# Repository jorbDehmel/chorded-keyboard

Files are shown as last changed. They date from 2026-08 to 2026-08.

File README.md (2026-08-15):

# USB-C Chorded Keyboard

Jordan Dehmel, 2026, MIT license

## About

This is a 10-key, one-handed chorded USB-C keyboard using a
scheme I made up. Each finger is responsible for two keys:
up and down. Only one is expected to be pressed down at a time.
Therefore, each of the 5 fingers has 3 states, leading to
$3^5 = 243$ combinations ($242$ if you don't count the empty
configuration). A chord will be denoted by a 5-character string,
with `U` meaning up, `D` meaning down, and `0` or space meaning
none. I will assume that the keyboard is being used in the left
hand, because I use a mouse in my right hand and therefore the
left is free. As such, we will use the string "`UUDD0`" to
denote the chord "pinky up, ring finger up, middle finger down,
pointer finger down, thumb not pressing either". We will use the
same string, even if the keyboard is being used in right-handed
mode.

The encoding scheme is really a separate project for me, I've
previously written drivers supporting it on QWERTY keyboards. I
just thought it would be cool to have a real version. This
keyboard is both chorded (each keystroke requires multiple
keys to be pressed) and corded (it is not bluetooth).

(If you're wondering why the pinky keys are so low, my
pinkies are just like that! They can't even reach the number
row or backslash on a regular keyboard.)

## The Schema

The idea with the included schema is to mimic the left hand's
QWERTY operations on home row and the row above as closely as
possible. The thumb is used to signify that the chord is
complete. Pressing down with the thumb is for regular
characters, while up is for unusual characters. In situations
where the regular character is not reachable on the two rows we
have access to, I've tried to make the chord look like an arrow
pointing to that character (for instance, "v" takes the chord
"`00UD D`", corresponding to pressing "r" and "f" at the same
time in QWERTY). For characters typed by the right hand in
QWERTY, I usually have a non-adjacent finger press some lower
key (for instance, "`D00D D`" for "j"). These can be combined
(for instance, "`D0DD D`" for "h" based on "`00DD D`" for "g").

 Chord    | Character
----------|-----------------------------------------------------
 `0000 U` | tab
 `000U U` | 8
 `000D U` | right arrow
 `00U0 U` | 4
 `00D0 U` | up arrow
 `0U00 U` | 2
 `0UU0 U` | 6
 `0D00 U` | down arrow
 `0DD0 U` | windows (or corresponding)
 `U000 U` | 1
 `U00U U` | 9
 `U0U0 U` | 5
 `UU00 U` | 3
 `UUU0 U` | 7
 `UUUU U` | escape
 `D000 U` | left arrow
 `DDDD U` | caps lock
 `0000 D` | space
 `000U D` | r
 `000D D` | f
 `00U0 D` | e
 `00UU D` | enter
 `00UD D` | v
 `00D0 D` | d
 `00DU D` | t
 `00DD D` | g
 `0U00 D` | w
 `0UU0 D` | backspace
 `0UUU D` | 0
 `0UD0 D` | c
 `0D00 D` | s
 `U000 D` | q
 `U00D D` | p
 `UD00 D` | x
 `UDUD D` | z
 `D000 D` | a
 `D00U D` | u
 `D00D D` | j
 `D0U0 D` | i
 `D0UD D` | b
 `D0D0 D` | k
 `D0DU D` | y
 `D0DD D` | h
 `DU00 D` | o
 `DUD0 D` | n
 `DUDU D` | m
 `DD00 D` | l

## The Physical Keyboard

This section describes how to assemble the core keyboard. This
is not ergonomic at all because it is intended to be modular.
However, the main module is all I have designed so far! If you
make any good ergonomic pieces, please let me know and/or pull
request them to this repo, they would be greatly appreciated!

### Parts List

In addition to the 3D-printable STL files included in this
directory, the following will be needed:

- 10x unlabelled keycaps (~$5)
- 10x mechanical keyboard switches (~$5)
- 1x USB-C Arduino Leonardo (EG [Pro Micro](https://www.amazon.com/gp/product/B0B81FGBLY)) (~$15)
- A bunch of wires (~$5)
- Soldering equipment (~$20)
- Optional grip tape (EG [this](https://www.amazon.com/Rubber-Strips-Solid-Sheets-Thick/dp/B0DDQG6J5F)) (~$10)

The arduino must have at least 10 input pins, at least 1 ground
pin, and support HID and the `INPUT_PULLUP` mode. It also must
be compatible with `Keyboard.h`, which not all boards are! Make
sure your arduino is compatible before going any further!

Also, obtain copies of the included STL parts. They should be
oriented in decent 3D-printing positions, but you will probably
need supports on the `Top.stl` part.

We will call the following piece the base or bottom case:

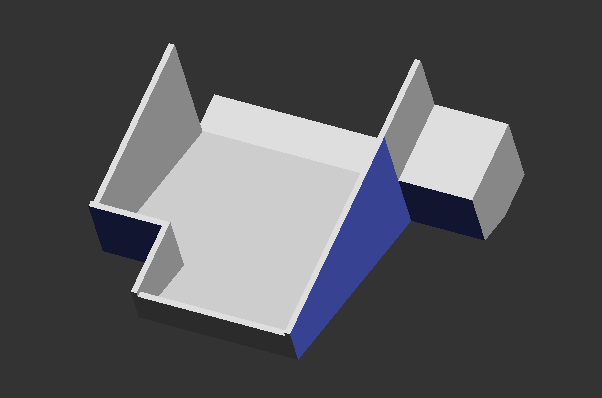
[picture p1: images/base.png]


And this piece the top or top case:

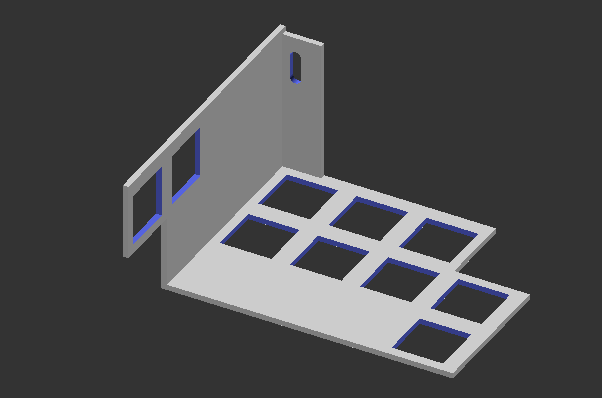
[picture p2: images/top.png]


The pieces should slot together like this:

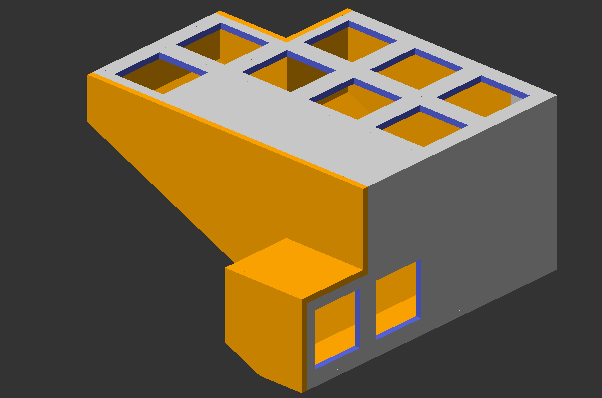
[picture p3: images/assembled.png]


Printing these two parts via my university cost me about $5. If
you start with absolutely nothing, the entire project should
cost about $60 to make. If you already have a 3D printer,
soldering equipment, and wires, it should cost about $25. The
arduino will be soldered to, so you should use one you don't
expect back.

The design is intended to (poorly) mimic my Logitech MX Ergo
upright trackball mouse, which I love dearly and highly
recommend for anyone who works with computers. The base is
designed to support a separate upright adapter in the same vein
as that mouse.

### Step 1: Assembling Keys

Slot the switches into the switch holes in the top casing. Make
sure that they are all in the same orientation **before**
slotting them in! The case is not designed to support removing
switches. Leave the keycaps off for now, or don't- I'm not your
mom.

### Step 2: Programming the Arduino

**Make sure to edit in the values of your pins!**

First, figure out what pins you will use. This uses 1 pin per
key: **Not** a matrix system, for chording reasons. There will
be 10 data pins used overall. **Edit `generate_arduino.py`** to
add them, then run that script. If you want to edit the schema,
you can use this script to do so.

Next, connect your **HID-compatible** arduino and upload the
sketch. This document details a corded chorded keyboard, which
requires HID for the `Keyboard.h` library. Notably, ESP32's are
not supported (though if you want to deal with batteries you
could easily use one to make a wireless version).

### Step 3: Soldering

Solder all the neutral pins of the keys together and to the
ground pin of the arduino. There should now be one pin remaining
on each switch. Solder a wire from each of these to a **unique**
digital input pin on the arduino (consult your board's pinout).
**Make sure you use the same pins you configured in step 2!**
Also ensure that no two keys are wired to the same arduino
input: They must be different. There should be a total of 11
wires soldered to your arduino: 1 ground and 10 data.





(please ignore my sloppy soldering, I bought a soldering iron
and learned to use it for this)

### Step 4: Testing and keycaps

Before you seal it up, connect your arduino to a computer, put
on the keycaps, and make sure all your joints are good. Test out
the chording schema while you're at it!

### Step 5: Final assembly

First, hot glue (or whatever) your arduino into place so that
its port goes out the port hole. If you want to do any wire
management with EG kapton tape, now is the time.

Now everything should be assembled in the upper case. The only
step remaining is to attach the 2 lower case components. You can
use glue if you don't mind replacing case parts every time you
need to open it, or you can use some heat-set threaded inserts
if you want more serviceability.



Quite a sleek little unit!

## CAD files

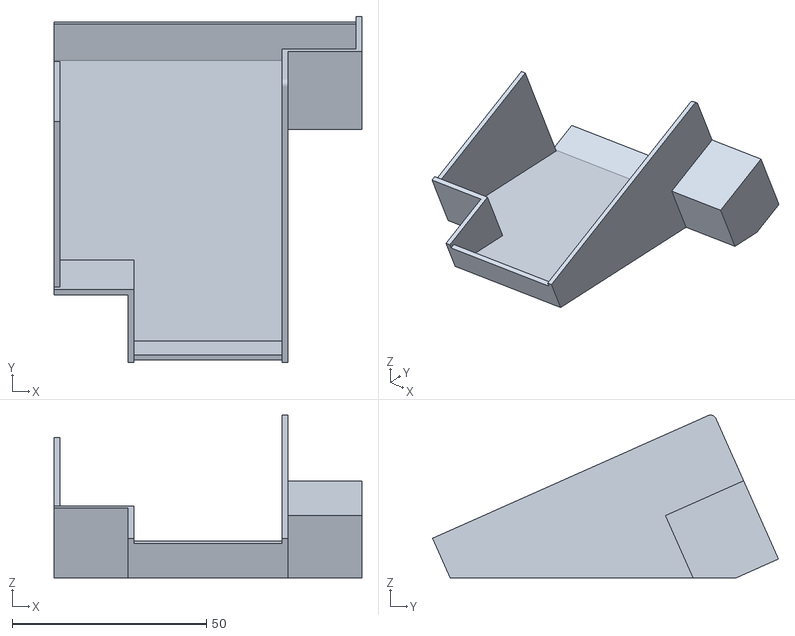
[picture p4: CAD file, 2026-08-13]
Base.stl
79.2 x 89.1 x 41.9

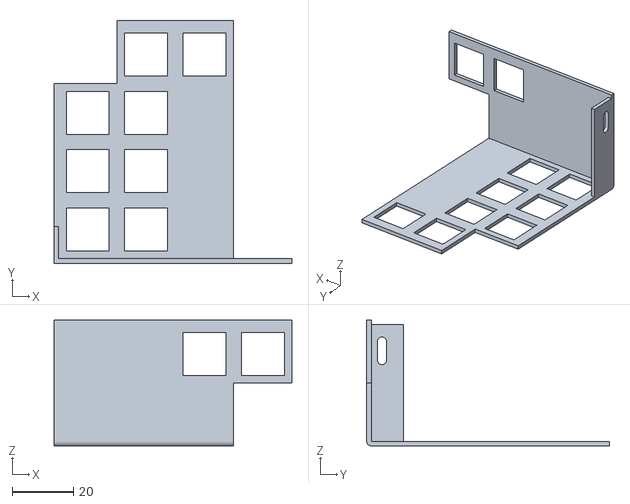
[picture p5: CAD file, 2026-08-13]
Top.stl
77.7 x 79.2 x 41.1

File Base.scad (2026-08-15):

//

include <Vars.scad>

$fn = $preview ? 32 : 64;

module base() {
  difference() {
    union() {
      // Bottom edge of pinky
      translate([
        switch_plate_w - thickness,
        -thickness,
        -spacing - thickness
      ])
        cube([
          2 * switch_plate_w + 2 * thickness,
          thickness,
          spacing + thickness
        ]);

      // Bottom edge of thumb
      translate([
        -thickness,
        4 * switch_plate_w - spacing - thickness,
        -2 * switch_plate_w - thickness
      ])
        cube([
          4 * switch_plate_w + 2 * thickness,
          spacing + thickness,
          thickness
        ]);

      // Baseplate bottom
      translate([
        -thickness,
        4 * switch_plate_w - 9 - thickness,
        -2 * switch_plate_w - thickness
      ])
        rotate([90 - rotation, 0, 0])
        cube([
          4 * switch_plate_w + 2 * thickness,
          thickness,
          4 * switch_plate_w - 2.641
        ]);

      // Walls around pinky
      translate([
        -thickness,
        -thickness,
        -switch_plate_w
      ])
        cube([
          switch_plate_w + thickness,
          switch_plate_w + thickness,
          switch_plate_w + thickness
        ]);

      // Back wall
      translate([
        3 * switch_plate_w,
        -thickness,
        -2 * switch_plate_w
      ])
        cube([
          thickness,
          3 * switch_plate_w + thickness,
          2 * switch_plate_w + thickness
        ]);

      // Front wall
      translate([
        -thickness,
        switch_plate_w,
        -2 * switch_plate_w
      ])
        cube([
          thickness,
          3 * switch_plate_w - 9 - thickness,
          2 * switch_plate_w
        ]);

      // Inner thumb wall
      translate([
        3 * switch_plate_w,
        -thickness,
        -2 * switch_plate_w
      ])
        cube([
          switch_plate_w + thickness,
          3 * switch_plate_w + thickness,
          switch_plate_w
        ]);

      // Back thumb wall
      translate([
        4 * switch_plate_w,
        switch_plate_w,
        -2 * switch_plate_w - thickness
      ])
        cube([
          thickness,
          3 * switch_plate_w + thickness,
          switch_plate_w + 2 * thickness
        ]);

      // Thumb cover
      translate([
        3 * switch_plate_w,
        3 * switch_plate_w,
        -switch_plate_w
      ])
        cube([
          thickness,
          switch_plate_w + thickness,
          switch_plate_w + thickness
        ]);

      translate([
        3 * switch_plate_w + thickness,
        3 * switch_plate_w - thickness,
        -switch_plate_w
      ])
        cube([
          switch_plate_w - thickness,
          switch_plate_w + 2 * thickness,
          thickness
        ]);
    }

    // Hole above pinky
    translate([
      -switch_plate_w - thickness,
      -switch_plate_w - thickness,
      -2 * switch_plate_w
    ])
      cube([
        2 * switch_plate_w,
        2 * switch_plate_w,
        3 * switch_plate_w
      ]);

    // Hole at base of thumb
    translate([
      3 * switch_plate_w + thickness,
      -2 * thickness,
      -3 * switch_plate_w
    ])
      cube([
        switch_plate_w + 2 * thickness,
        3 * switch_plate_w + thickness,
        5 * switch_plate_w
      ]);

    // Trim any junk below the base
    translate([
      -2 * thickness,
      4 * switch_plate_w - 9 - thickness,
      -2 * switch_plate_w - thickness
    ])
      rotate([90 - rotation, 0, 0])
      translate([0, -20 * thickness, 0])
      cube([
        4 * switch_plate_w + 20 * thickness,
        20 * thickness,
        4 * switch_plate_w + 20 * thickness
      ]);

    // Round off the peak
    translate([-2 * thickness, 4 * switch_plate_w, 0])
      rotate([0, 0, 0])
      edge_leveller(100, thickness);
  }
}

*rotate([rotation, 0, 0])
  translate([
    0,
    -4 * switch_plate_w + 9 + thickness,
    2 * switch_plate_w + thickness
  ])
  base();

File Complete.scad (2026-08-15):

// The casing for a chorded keyboard
// See: https://blog.arduino.cc/2023/06/05/build-your-own-wireless-hand-wired-keyboards-a-guide/

is_main = false;
include <Base.scad>
include <Top.scad>
include <Wedge.scad>

color("red")
  wedge();

translate([
  2 * thickness, // Exact
  2.1 * thickness, // Eyeballing it
  9
  ])
  rotate([wedge_rotation, 0, 0])
  rotate([rotation, 0, 0])
  union() {
    if (show_spacing) {
      color("blue")
        translate([0, 4 * switch_plate_w, -2 * switch_plate_w])
        rotate([90, 0, 0])
        arduino();
    }

    color("orange") base();
    top_piece();
  }

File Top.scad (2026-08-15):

//

include <Vars.scad>

// Model of arduino
module arduino() {
  arduino_width = 18;
  arduino_height = usb_c_female_height + 4;
  arduino_depth = 36;

  // Board
  cube([arduino_depth, arduino_width, arduino_height]);

  // USB-C female port 1 mm above base of board. I'll
  // put 2 for wiggle room
  translate([-usb_c_female_depth,
    (arduino_width - usb_c_female_width) / 2, 2])
    cube([usb_c_female_depth, usb_c_female_width,
      usb_c_female_height]);
}

// Tiling these next to each other is standard. See
// https://deskthority.net/viewtopic.php?t=20144
module keycap_mount() {
  delta = switch_plate_w - switch_hole_w;
  difference() {
    translate([-switch_plate_w / 2, -switch_plate_w / 2, 0])
      cube([switch_plate_w, switch_plate_w, thickness]);
    translate([
        -switch_plate_w / 2 + delta / 2,
        -switch_plate_w / 2 + delta / 2, -1])
      cube([switch_hole_w, switch_hole_w, thickness + 2]);
  }
  if (show_spacing) {
    color("blue")
      translate([-switch_plate_w / 2,
        -switch_plate_w / 2, -spacing])
      cube([switch_plate_w, switch_plate_w, spacing]);
  }
}

// The mounting for the two buttons corresponding to one
// finger
module finger_section_mount() {
  // Upper
  translate([switch_plate_w / 2, 0, 0])
    keycap_mount();
  // Lower
  translate([-switch_plate_w / 2, 0, 0])
    keycap_mount();
}

// The mounts for all the switches
module top_piece() {
  difference() {
    union () {
      // Pinky
      translate([
          2 * switch_plate_w,
          switch_plate_w / 2,
          0])
        finger_section_mount();

      // Main fingers
      for (d=[1, 2, 3]) {
        translate([
            switch_plate_w,
            d * switch_plate_w + switch_plate_w / 2,
            0])
          finger_section_mount();
      }

      // Thumb
      translate([
          3 * switch_plate_w,
          4 * switch_plate_w,
          -switch_plate_w / 2 - switch_plate_w])
        rotate([-90, 0, 0])
        finger_section_mount();

      // Between thumb and main mount
      translate([0, 4 * switch_plate_w, -2 * switch_plate_w])
        cube([
          2 * switch_plate_w,
          thickness,
          2 * switch_plate_w + thickness
        ]);

      // Going up from thumb
      translate([
        2 * switch_plate_w,
        4 * switch_plate_w,
        -switch_plate_w
      ])
        cube([
          switch_plate_w,
          thickness,
          switch_plate_w + thickness
        ]);

      // Going from pinky to the previous part
      translate([2 * switch_plate_w, switch_plate_w, 0])
        cube([switch_plate_w, 3 * switch_plate_w, thickness]);

      // Bottom lining under thumb
      translate([
        0,
        4 * switch_plate_w,
        -2 * switch_plate_w - thickness
      ])
        cube([4 * switch_plate_w, thickness, thickness]);

      // Bottom lining under pinky
      translate([switch_plate_w, -thickness, 0])
        cube([2 * switch_plate_w, thickness, thickness]);

      // Front panel
      translate([
        -thickness,
        4 * switch_plate_w,
        -2 * switch_plate_w - thickness
      ])
        cube([thickness, thickness, thickness]);

      translate([
        -thickness,
        switch_plate_w,
        0
      ])
        cube([thickness, 3 * switch_plate_w, thickness]);

      // This is the part with the USB-C hole
      difference() {
        translate([
          -thickness,
          4 * switch_plate_w - 9 - thickness,
          -2 * switch_plate_w
        ])
          cube([
            thickness,
            9 + 2 * thickness,
            2 * switch_plate_w + thickness
          ]);

        // USB-C hole
        translate([
          -2 * thickness,
          4 * switch_plate_w - thickness - 2,
          -switch_plate_w - usb_c_female_width
          + usb_c_female_height / 2
        ])
          rotate([0, 90, 0])
          union() {
            cylinder(
              h=2 * usb_c_female_depth,
              r=usb_c_female_height / 2
            );

            translate([
              usb_c_female_width - usb_c_female_height,
              0,
              0
            ])
              cylinder(
                h=2 * usb_c_female_depth,
                r=usb_c_female_height / 2
              );

            translate([0, -usb_c_female_height / 2, 0])
              cube([
                usb_c_female_width - usb_c_female_height,
                usb_c_female_height,
                2 * usb_c_female_depth
              ]);
          };
      }
    }
    translate([-2 * thickness, 4 * switch_plate_w, 0])
      rotate([0, 0, 0])
      edge_leveller(100, thickness);
  }
}

*translate([0, 0, thickness])
  rotate([180, 0, 0])
  top_piece();

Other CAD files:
Vars.scad
Wedge.scad

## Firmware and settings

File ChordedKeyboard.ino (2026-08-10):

#include <Keyboard.h>
#include <schema.hpp>

const static int pinky_up_pin = 13;
const static int pinky_down_pin = 12;
const static int ring_up_pin = 14;
const static int ring_down_pin = 27;
const static int middle_up_pin = 26;
const static int middle_down_pin = 25;
const static int pointer_up_pin = 33;
const static int pointer_down_pin = 32;
const static int thumb_up_pin = 35;
const static int thumb_down_pin = 34;
const static int light_pin = 23;

void setup() {
  for (const auto &pin :
       {pinky_up_pin, pinky_down_pin, ring_up_pin,
        ring_down_pin, middle_up_pin, middle_down_pin,
        pointer_up_pin, pointer_down_pin, thumb_up_pin,
        thumb_down_pin}) {
    pinMode(pin, INPUT);
  }
  pinMode(light_pin, OUTPUT);

  Keyboard.begin();
}

// Given the current state, return what key should
// be sent, or -1 if none. There are 3^4 * 2 chords,
// since the thumb must always engage and the other
// four fingers each have three states. The string
// "0UD0U" here means pinky off, ring up, middle
// down, pointer off, thumb up. Read it like a left
// hand.
int get_key(const struct Chord &_state) {
  switch (_state.thumb) {
  case OFF:
    return -1;
  case UP:
    switch (_state.pinky) {
    case OFF:
      switch (_state.ring) {
      case OFF:
        switch (_state.middle) {
        case OFF:
          switch (_state.pointer) {
          case OFF:
            // 0000 U - 0
            return KEY_TAB;
          case UP:
            // 000U U - 8
            return '8';
          case DOWN:
            // 000D U - right arrow
            return KEY_RIGHT_ARROW;
          }
        case UP:
          switch (_state.pointer) {
          case OFF:
            // 00U0 U - 4
            return '4';
          default:
            return -1;
          }
        case DOWN:
          switch (_state.pointer) {
          case OFF:
            // 00D0 U - up arrow
            return KEY_UP_ARROW;
          default:
            return -1;
          }
        }
      case UP:
        switch (_state.middle) {
        case OFF:
          switch (_state.pointer) {
          case OFF:
            // 0U00 U - 2
            return '2';
          default:
            return -1;
          }
        case UP:
          switch (_state.pointer) {
          case OFF:
            // 0UU0 U - 6
            return '6';
          default:
            return -1;
          }
        case DOWN:
          return -1;
        }
      case DOWN:
        switch (_state.middle) {
        case OFF:
          switch (_state.pointer) {
          case OFF:
            // 0D00 U - down arrow
            return KEY_DOWN_ARROW;
          default:
            return -1;
          }
        case DOWN:
          switch (_state.pointer) {
          case OFF:
            // 0DD0 U - windows
            return KEY_HOME;
          default:
            return -1;
          }
        default:
          return -1;
        }
      }
    case UP:
      switch (_state.ring) {
      case OFF:
        switch (_state.middle) {
        case OFF:
          switch (_state.pointer) {
          case OFF:
            // U000 U - 1
            return '1';
          case UP:
            // U00U U - 9
            return '9';
          case DOWN:
            return -1;
          }
        case UP:
          switch (_state.pointer) {
          case OFF:
            // U0U0 U - 5
            return '5';
          default:
            return -1;
          }
        case DOWN:
          return -1;
        }
      case UP:
        switch (_state.middle) {
        case OFF:
          switch (_state.pointer) {
          case OFF:
            // UU00 U - 3
            return '3';
          default:
            return -1;
          }
        case UP:
          switch (_state.pointer) {
          case OFF:
            // UUU0 U - 7
            return KEY_UP_ARROW;
            return '7';
          case UP:
            // UUUU U - escape
            return KEY_ESC;
          case DOWN:
            return -1;
          }
        case DOWN:
          return -1;
        }
      case DOWN:
        return -1;
      }
    case DOWN:
      switch (_state.ring) {
      case OFF:
        switch (_state.middle) {
        case OFF:
          switch (_state.pointer) {
          case OFF:
            // D000 U - left arrow
            return KEY_LEFT_ARROW;
          case UP:
            return -1;
          case DOWN:
            // D00D U - ctrl
            // return KEY_CTRL;
            return -1;
          }
        default:
          return -1;
        }
      case UP:
        return -1;
      case DOWN:
        switch (_state.middle) {
        case DOWN:
          switch (_state.pointer) {
          case DOWN:
            // DDDD U - caps lock
            return KEY_CAPS_LOCK;
          default:
            return -1;
          }
        default:
          return -1;
        }
      }
    }
  case DOWN:
    switch (_state.pinky) {
    case OFF:
      switch (_state.ring) {
      case OFF:
        switch (_state.middle) {
        case OFF:
          switch (_state.pointer) {
          case OFF:
            // 0000 D - space
            return ' ';
          case UP:
            // 000U D - r
            return 'r';
          case DOWN:
            // 000D D - f
            return 'f';
          }
        case UP:
          switch (_state.pointer) {
          case OFF:
            // 00U0 D - e
            return 'e';
          case UP:
            // 00UU D - enter
            return KEY_RETURN;
          case DOWN:
            // 00UD D - v
            return 'v';
          }
        case DOWN:
          switch (_state.pointer) {
          case OFF:
            // 00D0 D - d
            return 'd';
          case UP:
            // 00DU D - t
            return 't';
          case DOWN:
            // 00DD D - g
            return 'g';
          }
        }
      case UP:
        switch (_state.middle) {
        case OFF:
          switch (_state.pointer) {
          case OFF:
            // 0U00 D - w
            return 'w';
          case UP:
            return -1;
          case DOWN:
            return -1;
          }
        case UP:
          switch (_state.pointer) {
          case OFF:
            // 0UU0 D - backspace
            return KEY_BACKSPACE;
          case UP:
            // 0UUU D - 0
            return '0';
          case DOWN:
            return -1;
          }
        case DOWN:
          // 0UD0 D - c
          switch (_state.pointer) {
          case OFF:
            return 'c';
          default:
            return -1;
          }
        }
      case DOWN:
        switch (_state.middle) {
        case OFF:
          switch (_state.pointer) {
          case OFF:
            // 0D00 D - s
            return 's';
          default:
            return -1;
          }
        default:
          return -1;
        }
      }
    case UP:
      switch (_state.ring) {
      case OFF:
        switch (_state.middle) {
        case OFF:
          switch (_state.pointer) {
          case OFF:
            // U000 D - q
            return 'q';
          case UP:
            return -1;
          case DOWN:
            // U00D D - p
            return 'p';
          }
        default:
          return -1;
        }
      case UP:
        return -1;
      case DOWN:
        switch (_state.middle) {
        case OFF:
          switch (_state.pointer) {
          case OFF:
            // UD00 D - x
            return 'x';
          default:
            return -1;
          }
        case UP:
          switch (_state.pointer) {
          case DOWN:
            // UDUD D - z
            return 'z';
          default:
            return -1;
          }
        case DOWN:
          return -1;
        }
      }
    case DOWN:
      switch (_state.ring) {
      case OFF:
        switch (_state.middle) {
        case OFF:
          switch (_state.pointer) {
          case OFF:
            // D000 D - a
            return 'a';
          case UP:
            // D00U D - u
            return 'u';
          case DOWN:
            // D00D D - j
            return 'j';
          }
        case UP:
          switch (_state.pointer) {
          case OFF:
            // D0U0 D - i
            return 'i';
          case UP:
            return -1;
          case DOWN:
            // D0UD D - b
            return 'b';
          }
        case DOWN:
          switch (_state.pointer) {
          case OFF:
            // D0D0 D - k
            return 'k';
          case UP:
            // D0DU D - y
            return 'y';
          case DOWN:
            // D0DD D - h
            return 'h';
          }
        }
      case UP:
        switch (_state.middle) {
        case OFF:
          switch (_state.pointer) {
          case OFF:
            // DU00 D - o
            return 'o';
          default:
            return -1;
          }
        case UP:
          return -1;
        case DOWN:
          switch (_state.pointer) {
          case OFF:
            // DUD0 D - n
            return 'n';
          case UP:
            // DUDU D - m
            return 'm';
          case DOWN:
            return -1;
          }
        }
      case DOWN:
        switch (_state.middle) {
        case OFF:
          switch (_state.pointer) {
          case OFF:
            // DD00 D - l
            return 'l';
          default:
            return -1;
          }
        default:
          return -1;
        }
      }
    }
  }
}

void loop() {
  Chord state;
  state.pinky = state.ring = state.middle = state.pointer =
      state.thumb = OFF;

  if (digitalRead(pinky_up_pin) == HIGH) {
    state.pinky = UP;
  } else if (digitalRead(pinky_down_pin) == HIGH) {
    state.pinky = DOWN;
  }
  if (digitalRead(ring_up_pin) == HIGH) {
    state.ring = UP;
  } else if (digitalRead(ring_down_pin) == HIGH) {
    state.ring = DOWN;
  }
  if (digitalRead(middle_up_pin) == HIGH) {
    state.middle = UP;
  } else if (digitalRead(middle_down_pin) == HIGH) {
    state.middle = DOWN;
  }
  if (digitalRead(pointer_up_pin) == HIGH) {
    state.pointer = UP;
  } else if (digitalRead(pointer_down_pin) == HIGH) {
    state.pointer = DOWN;
  }
  if (digitalRead(thumb_up_pin) == HIGH) {
    state.thumb = UP;
  } else if (digitalRead(thumb_down_pin) == HIGH) {
    state.thumb = DOWN;
  }

  const int key = default_schema.get_key(state);
  if (key > 0) {
    digitalWrite(light_pin, HIGH);
    Keyboard.press(key);
  } else {
    digitalWrite(light_pin, LOW);
    Keyboard.releaseAll();
  }
}

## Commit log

2026-08-11 Fixed C++ training program
    [ChordedKeyboard.ino]
2026-08-11 Arduino compatability
2026-08-12 Switched to python script that generates the sketch
2026-08-13 Docs, added rounded edge to casing
    [Base.stl, Complete.scad, Top.stl]
2026-08-15 Added images
    [Base.scad, Complete.scad, Top.scad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]
2026-08-15 Added CTRL, shift, etc. functionality. Also fixed compound chord spamming
    [ChordedKeyboard.ino]
2026-08-21 Fixed wasd and arrows modes
    [ChordedKeyboard.ino]
